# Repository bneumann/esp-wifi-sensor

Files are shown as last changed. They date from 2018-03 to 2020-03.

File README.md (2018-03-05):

# Temperature/Humidity Sensor SHT21 with ESP8266
There are a lot of IOT sensor projects out there. Why would I do my own one? First: Because I can and the fun it brings. Or frustration. Or a bit of both. Second, I was looking for a decent driver that actually works with the SHT21. None of the stock Adafruit libraries worked for me. And when I checked my logic analyzer all the drives had the same bug.
SO: I also wrote my own driver. Later on I ported it to the ESP-01 which only has 2 Pins available so I bit banged my own i2c driver too.
Maybe some people can learn from the code (sorry for the sparse comments), that's why I put it online. Feel free to ask questions!

I also provide my layout file which I use for the sensors in my house.

## Wifi credentials
Because I don't want you guys to spoof around my wifi, I didn't check in the credentials. Clever ey? So you will need to create your own `credentials.h` file in the base directory:
```c
#define WLAN_SSID       "YOURID"
#define WLAN_PASS       "YOURPW"
#define DEVICE_NAME     "bathroom"
#define AIO_SERVER      "servername"
#define AIO_SERVERPORT  1883
```

## I2C driver
As I said, that one is simple bit banging the basic start, stop, read and write methods. Check the header file `i2c.h` for available methods. Might be a cool starting point if you want your own sensor or peripheral and only have 2 pins.

## SHT21 driver
On top of the i2c driver sits the SHT21 driver using the no hold measurement. Which basically means, that I am polling the lil fella until he's done measuring.
All my SHT21s I have didn't work with the Adafruit driver which uses the hold measurement. They pull down the clock line until the SHT21 is done measuring and continue from there. 
The driver contains of a few basic steps:
```c
// Create a callback method
void measurementDoneCb(const uint16_t *temp, const  uint16_t *humid)
{
  if (*temp && *humid) {
    // do what you want with the data
  }
}
/* .... other code .... */
// initialise SHT
sht_init(); // takes about 15ms
// Trigger a measurement
sht_trigger_measurement(TRG_TEMP_MEAS_NO_HOLD, measurementDoneCb);
// Trigger another one. You could do that in the callback if you want too
sht_trigger_measurement(TRG_HUMI_MEAS_NO_HOLD, measurementDoneCb);
```

### Sensor data conversion
The data from the sensor is some digital data. You need to calculate it using these formulas. I conveniently put them into C code already:
```c
float calculateTemperature(uint16_t temp) {
  return -46.85 + 175.72 * ((float)temp) / 65536.0;
}

float calculateHumidity(uint16_t temp) {
  return -6.0 + 125.0 * ((float)temp) / 65536.0;
}
```

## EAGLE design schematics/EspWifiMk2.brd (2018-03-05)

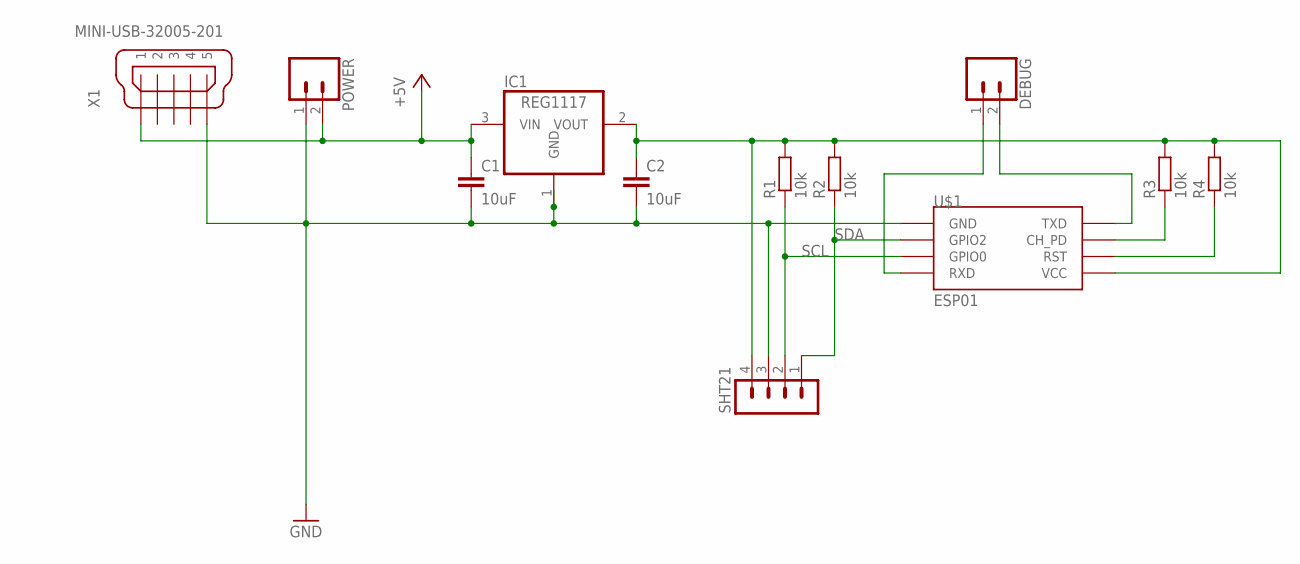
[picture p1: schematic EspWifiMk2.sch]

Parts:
C1, C2: 10uF; C1206
DEBUG: CONN_02; 1X02
IC1: REG1117; SOT223
POWER: CONN_02; 1X02
R1, R2, R3, R4: 10k; M1206
SHT21: MA04-1
U$1: ESP01
X1: MINI-USB-32005-201; 32005-201

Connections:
3V3: C2.1, IC1.2 (VOUT), R1.2, R2.2, R3.2, R4.2, SHT21.4, U$1.VCC
+5V: C1.1, IC1.3 (VIN), POWER.2, X1.1
GND: C1.2, C2.2, IC1.1 (GND), POWER.1, SHT21.3, U$1.GND, X1.5
unnamed: R3.1, U$1.CH_PD
unnamed: R4.1, U$1.RST
unnamed: DEBUG.1, U$1.RX (RXD)
unnamed: DEBUG.2, U$1.TX (TXD)
SCL: R1.1, SHT21.2, U$1.GPIO0
SDA: R2.1, SHT21.1, U$1.GPIO2

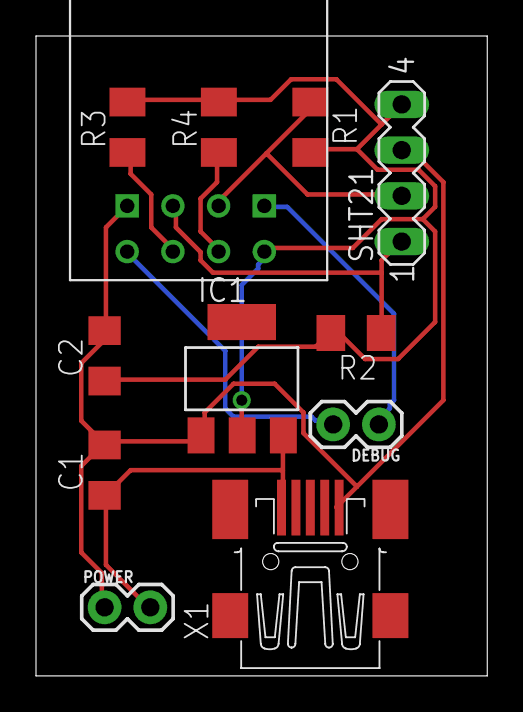
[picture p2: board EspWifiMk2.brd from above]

Board: 2 copper layers, 25.1 x 35.5 mm, 12 parts (0 on the bottom side), 9 nets.

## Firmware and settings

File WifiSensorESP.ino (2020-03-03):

#include "sht21.h"
#include "credentials.h"
#include <ESP8266WiFi.h>
#include "Adafruit_MQTT.h"
#include "Adafruit_MQTT_Client.h"

#define PRODUCTION

// DEFINES

// CREATE A credentials.h HEADER FILE WITH THESE DEFINES:
// #define WLAN_SSID       "YOURID"
// #define WLAN_PASS       "YOURPW"
// #define DEVICE_NAME     "bathroom"
// #define AIO_SERVER      "servername"
// #define AIO_SERVERPORT  1883

#define SLEEP_TIME 300
#define MAX_WIFI_CONNECT_RETRIES 20
#define MAX_MEASURE_RETRIES 10

// MACROS
#define TOPIC(location, type) "sensor/" location "/" type
#define TEMP_TOPIC TOPIC(DEVICE_NAME, "temperature")
#define HUMID_TOPIC TOPIC(DEVICE_NAME, "humidity")
#ifndef PRODUCTION
#undef SLEEP_TIME
#define SLEEP_TIME 30
#define DEVICE_NAME "DEBUG_SENSOR"
#define DEBUG_TOPIC TOPIC(DEVICE_NAME, "debug")
#endif
#define HOST_NAME "esp_sensor_" DEVICE_NAME

// FORWARD DECLARATIONS
void MQTT_connect();

// GLOBALS
WiFiClient client;
Adafruit_MQTT_Client mqtt(&client, AIO_SERVER, AIO_SERVERPORT);
Adafruit_MQTT_Publish temperatureTopic = Adafruit_MQTT_Publish(&mqtt, TEMP_TOPIC);
Adafruit_MQTT_Publish humidityTopic = Adafruit_MQTT_Publish(&mqtt, HUMID_TOPIC);
#ifndef PRODUCTION
Adafruit_MQTT_Publish debugTopic = Adafruit_MQTT_Publish(&mqtt, DEBUG_TOPIC);
#endif

// USER FUNCTIONS
void sleep(long sleeptime)
{
  WiFi.disconnect();  
  Serial.print("Sleeping for ");
  Serial.print(sleeptime);
  Serial.println(" seconds");
  //1,000,000 = 1 second
  ESP.deepSleep(1000000 * sleeptime);
}

float calculateTemperature(uint16_t temp)
{
  return -46.85 + 175.72 * ((float)temp) / 65536.0;
}

float calculateHumidity(uint16_t temp)
{
  return -6.0 + 125.0 * ((float)temp) / 65536.0;
}

void measurementDoneCb(const uint16_t *temp, const uint16_t *humid)
{
  static int deathCount = 0;
  Serial.println("Meas cb called");
  if (*temp && *humid)
  {
    mqttPublish(calculateTemperature(*temp), calculateHumidity(*humid));
    sleep(SLEEP_TIME); // sleep 5 minutes
  }
  if(deathCount++ > MAX_MEASURE_RETRIES)
  {
    deathCount = 0;
    Serial.println("Sensor not found");
    #ifndef PRODUCTION
    MQTT_connect();
    debugTopic.publish(42);
    mqtt.disconnect();
    #endif
    sleep(SLEEP_TIME); // sleep 5 minutes
  }
}

// Function to connect and reconnect as necessary to the MQTT server.
// Should be called in the loop function and it will take care if connecting.
void MQTT_connect()
{
  int8_t ret;

  // Stop if already connected.
  if (mqtt.connected())
  {
    Serial.print("Already connected to MQTT...");
    return;
  }

  Serial.print("Connecting to MQTT... ");

  uint8_t retries = 3;
  while ((ret = mqtt.connect()) != 0)
  { // connect will return 0 for connected
    Serial.println(mqtt.connectErrorString(ret));
    Serial.println("Retrying MQTT connection in 5 seconds...");
    mqtt.disconnect();
    delay(5000); // wait 5 seconds
    retries--;
    if (retries == 0)
    {
      // basically die and wait for WDT to reset me
      while (1)
        ;
    }
  }

  Serial.println("MQTT Connected!");
}

void mqttPublish(float temperature, float humidity)
{
  Serial.print(TEMP_TOPIC);
  Serial.println(temperature);
  Serial.print(HUMID_TOPIC);
  Serial.println(humidity);
  MQTT_connect();

  temperatureTopic.publish(temperature);
  humidityTopic.publish(humidity);
  delay(1000);

  // ping the server to keep the mqtt connection alive
  if (!mqtt.ping())
  {
    mqtt.disconnect();
  }
}

// SETUP AND LOOP
void setup()
{
  Serial.begin(115200);
  // put your setup code here, to run once:
#ifdef PRODUCTION
  Serial.println("Production mode");
#else
  Serial.setDebugOutput(true);
  Serial.println("Development mode");
  WiFi.printDiag(Serial);
#endif

  Serial.println("Set to STA mode");
  WiFi.mode(WIFI_STA);

  Serial.print("Scan start ... ");
  int n = WiFi.scanNetworks();
  Serial.print(n);
  Serial.println(" network(s) found");
  for (int i = 0; i < n; i++)
  {
    Serial.println(WiFi.SSID(i));
  }

  Serial.print("Connecting to ");
  Serial.println(WLAN_SSID);
  WiFi.begin(WLAN_SSID, WLAN_PASS);
  WiFi.hostname(HOST_NAME);
  int retry = MAX_WIFI_CONNECT_RETRIES;
  while (WiFi.status() != WL_CONNECTED)
  {
    delay(1000);
    Serial.print(".");
    if(retry-- == 0)
    {
      sleep(30);
    }
  }

  Serial.println("");
  Serial.println("WiFi connected");
  Serial.println("IP address: ");
  Serial.println(WiFi.localIP());
  sht_init();
}

void loop()
{
  // put your main code here, to run repeatedly:
  sht_trigger_measurement(TRG_TEMP_MEAS_NO_HOLD, measurementDoneCb);
  delay(1000);
  sht_trigger_measurement(TRG_HUMI_MEAS_NO_HOLD, measurementDoneCb);
  delay(1000);
}

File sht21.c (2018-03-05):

/*
   i2c.c

    Created on: 15.01.2017
        Author: benni
*/

#include "sht21.h"

#include <Arduino.h>
#include "i2c.h"

#define READ_FLAG 1
#define MEAS_TIME 150 ///< Measurement time in ms
#define MEAS_AND_CHECK 2 ///< Read 2 databytes and the checksum
// #define ICACHE_FLASH_ATTR

typedef struct {
  uint16_t temperature;
  uint16_t humidity;
  uint16_t checksum;
  uint8_t retries;
  bool running;
  tSht21MeasureTypes type;
} tSht21Context;

static MeasurementDoneHandler userCallback;
static tSht21Context tContext = {0, 0, 0, 0, false, TRG_TEMP_MEAS_NO_HOLD};

static bool sht_measurement_done();

typedef enum {
  ADDRESS 				= 0x80,
  TRG_TEMP_MEAS_HOLD 		= 0xE3,
  TRG_HUMI_MEAS_HOLD 		= 0xE5,
  //	TRG_TEMP_MEAS_NO_HOLD 	= 0xF3,
  //	TRG_HUMI_MEAS_NO_HOLD 	= 0xF5,
  WRITE_USER_REG			= 0xE6,
  READ_USER_REG			= 0xE7,
  TRG_SOFT_RESET			= 0xFE
} tSht21Defines;



static void  measureTimerCb()
{
  bool ack = sht_measurement_done();
  // If the measurement is already done we call the users callback otherwise we wait
  if (!ack)
  {
    if (tContext.retries++ > 3)
    {
      tContext.running = false;
      sht_soft_reset();
      tContext.retries = 0;
      if (userCallback != NULL)
      {
        userCallback(&tContext.temperature, &tContext.humidity);
      }
      return;
    }
    delay(150);
    measureTimerCb();
  }
  else
  {
    tContext.running = false;
    sht_soft_reset();
    tContext.retries = 0;
    //		printf("meas  done, calling user\n");
    if (userCallback != NULL)
    {
      userCallback(&tContext.temperature, &tContext.humidity);
    }
  }
}

// Interface methods
void sht_init()
{
  i2c_init();
  delay(15);
}

bool sht_trigger_measurement(tSht21MeasureTypes type, MeasurementDoneHandler cb)
{
  bool ret = false;
  if (!tContext.running)
  {
    tContext.running = true;
    tContext.type = type;
    userCallback = cb;
    bool ret;
    i2c_start();
    ret = i2c_write(ADDRESS);
    if (i2c_write(type)) {
      delayMicroseconds(20);
    }
    i2c_stop();
    delay(1);
    measureTimerCb();
    ret = true;
  }
  return ret;
}

static bool sht_measurement_done()
{
  bool ack = false;
  if (tContext.running)
  {
    uint16 *data = tContext.type == TRG_TEMP_MEAS_NO_HOLD ? &tContext.temperature : &tContext.humidity;
    i2c_start();
    ack = i2c_write(ADDRESS | READ_FLAG);
    if (ack)
    {
      uint8_t meas;
      *data = 0;
      for (meas = 0; meas <= MEAS_AND_CHECK; meas++)
      {
        uint8_t tmp = i2c_read(meas < MEAS_AND_CHECK);
        if (meas < MEAS_AND_CHECK) {
          *data |= tmp << (MEAS_AND_CHECK - meas - 1) * 8;
          //				printf("we received: %d\n", tmp);
        }
      }
    }
    i2c_stop();
    // Clear last two bits
    // TODO: Use last bits to retrieve which measurement has been started
    *data &= ~0x02;
  }
  return ack;
}

bool sht_soft_reset()
{
  // FIXME: Add reset time of 15 ms where no
  // communication can be established after reset.
  // Sending data in the reset time can render the
  // sensor inoperable until the next restart.
  return true;
  if (!tContext.running)
  {
    i2c_start();
    i2c_write(ADDRESS);
    i2c_write(TRG_SOFT_RESET);
    i2c_stop();
    return true;
  }
  return false;
}

tShtSettings  sht_get_user()
{
  i2c_start();
  i2c_write(ADDRESS);
  i2c_write(READ_USER_REG);
  i2c_start();
  i2c_write(ADDRESS | READ_FLAG);
  byte readVal = i2c_read(true);
  i2c_stop();
  tShtSettings ret = {0, 0, 0, 0};
  ret.BatteryState = (readVal >> 6) & 0x01;
  ret.DisableOtpReaload = (readVal >> 1) & 0x01;
  ret.EnableHeater = (readVal >> 2) & 0x01;
  ret.MeasResolution = ((readVal >> 6) & 0x02) | (readVal & 0x01);
  return ret;
}

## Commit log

2018-03-05 Added basic README and fixed define
    [WifiSensorESP.ino, sht21.c]
2018-03-05 Filled readme, cosmetics
    [EspWifiMk2.brd, EspWifiMk2.sch]
2018-03-05 Fixed drawings in i2c
    [i2c.c]
2019-04-16 Added debugging information in case of Development switch
2019-04-16 Reenabled correct measured data
    [WifiSensorESP.ino]
2020-03-03 improved power saving

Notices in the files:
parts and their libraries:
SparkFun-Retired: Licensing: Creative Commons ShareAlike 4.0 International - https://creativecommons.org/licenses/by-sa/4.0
